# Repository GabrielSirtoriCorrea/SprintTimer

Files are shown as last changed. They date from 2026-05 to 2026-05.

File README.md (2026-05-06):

# SprintTimer
O projeto consiste em um cronômetro destinado à medição de tempos de atletas durante treinamentos de futebol. O sistema baseia-se em um sensor ultrassônico, responsável por detectar a ultrapassagem do atleta em uma marca predefinida, com base na medição de distância. , Um arduino realizará o processamento dos dados para registrar os tempos.

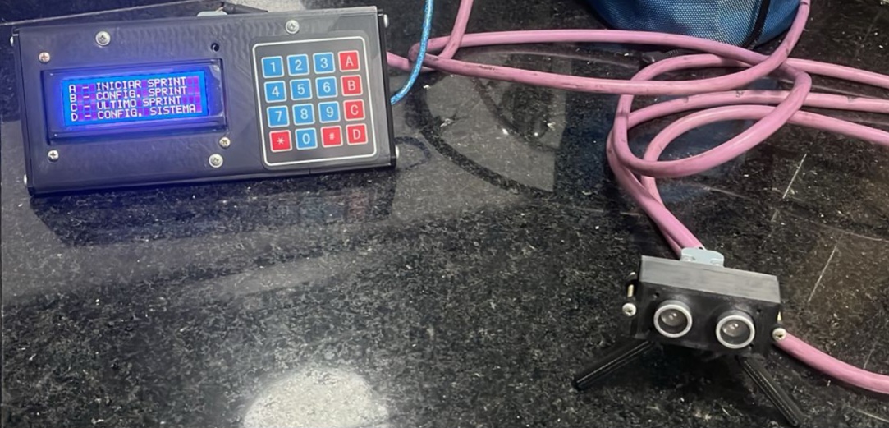
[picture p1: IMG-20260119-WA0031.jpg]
Final

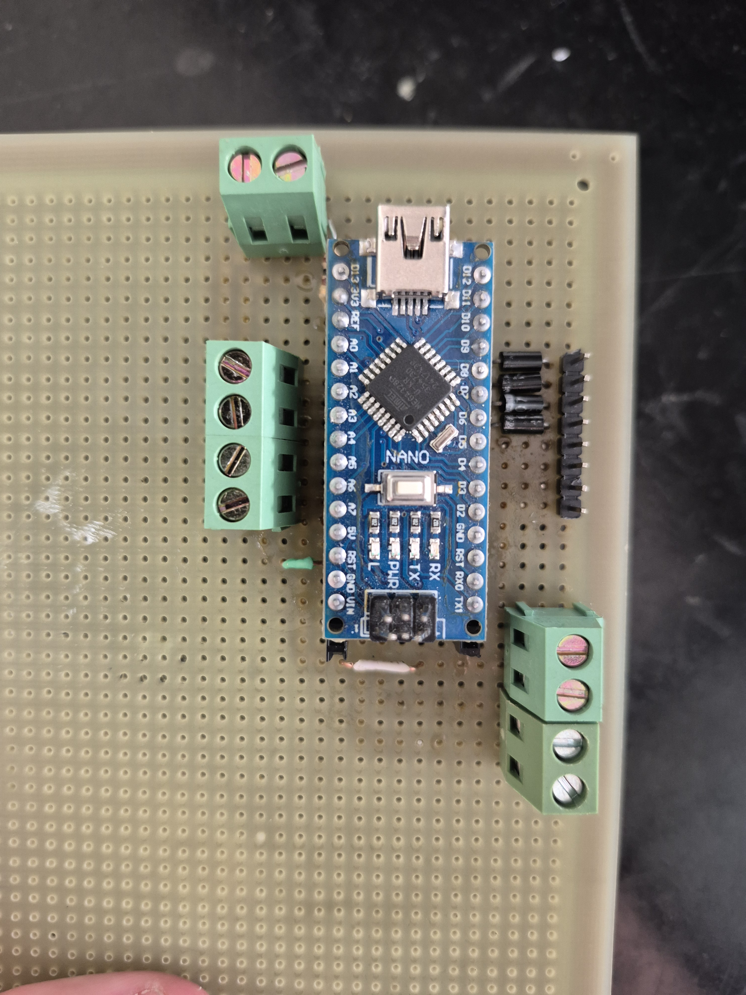
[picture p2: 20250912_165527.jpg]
Circuito Montado

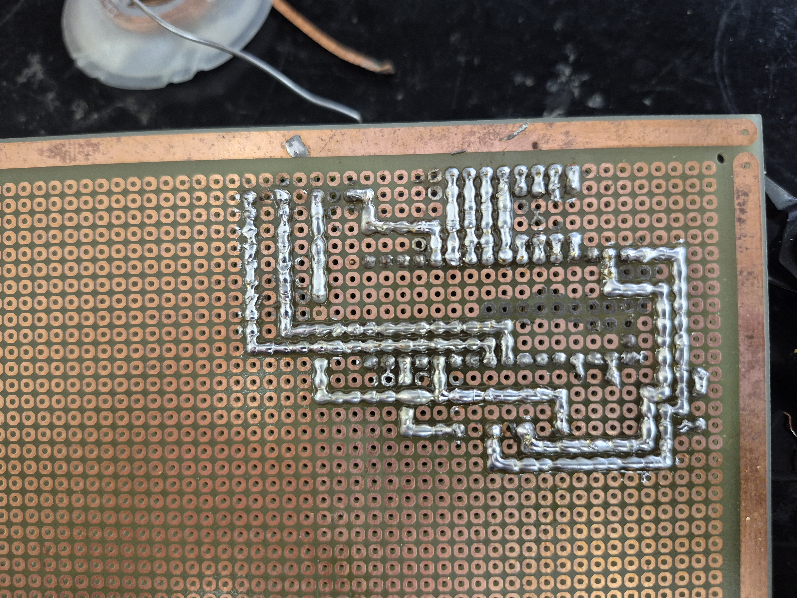
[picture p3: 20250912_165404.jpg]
Solda

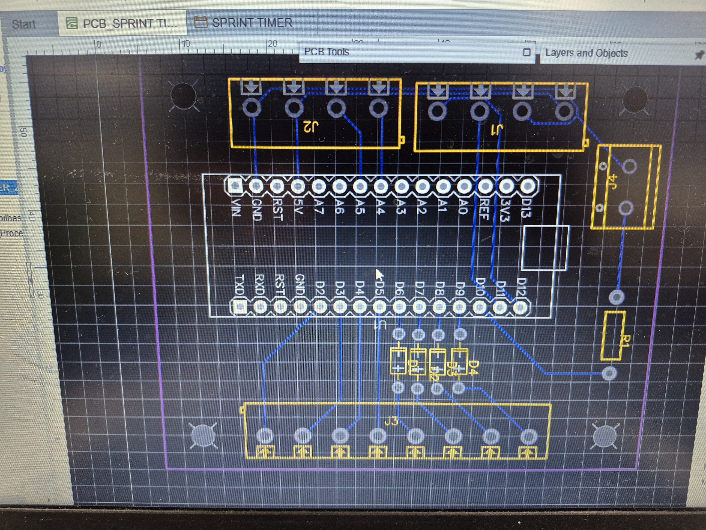
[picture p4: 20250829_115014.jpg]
Projeto


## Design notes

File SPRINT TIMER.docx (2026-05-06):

SPRINT TIMER

Projeto: Gabriel Sirtori Corrêa

Destinado a: Ricardo Roquetti

O presente projeto propõe a criação de um cronômetro destinado à medição de tempos de atletas durante treinamentos de futebol. O sistema será baseado em um sensor ultrassônico, responsável por detectar a ultrapassagem do atleta por uma marca predefinida, com base na medição de distância. As informações captadas pelo sensor serão enviadas a um Arduino Nano, que realizará o processamento dos dados para registrar os tempos com precisão.

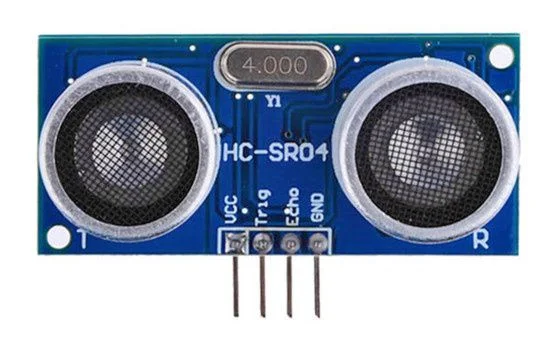
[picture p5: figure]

Sensor ultrassônico a ser utilizado no projeto

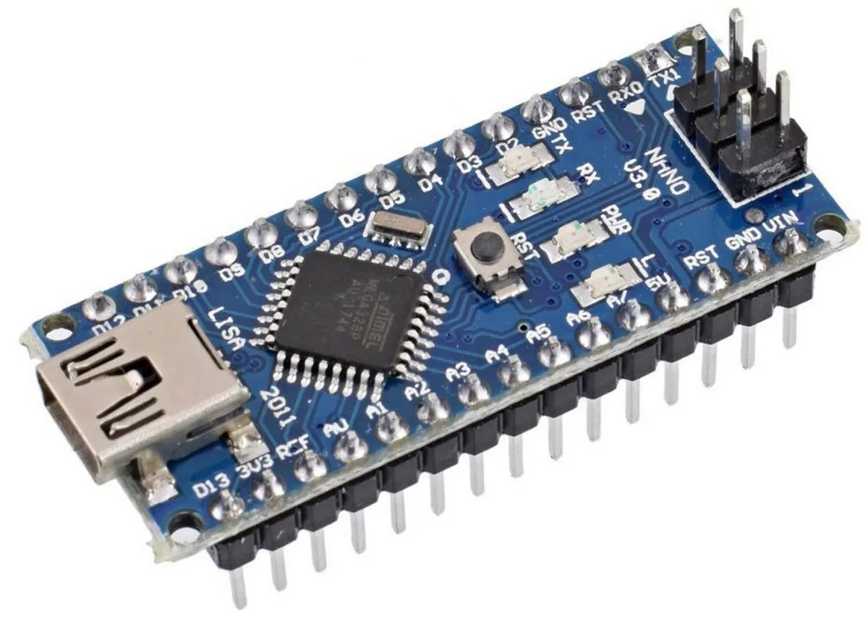
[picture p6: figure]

Arduino nano a ser utilizado no projeto

Junto ao arduino, será conectado um display LCD 20x4 junto a um módulo I2C para comunicação.

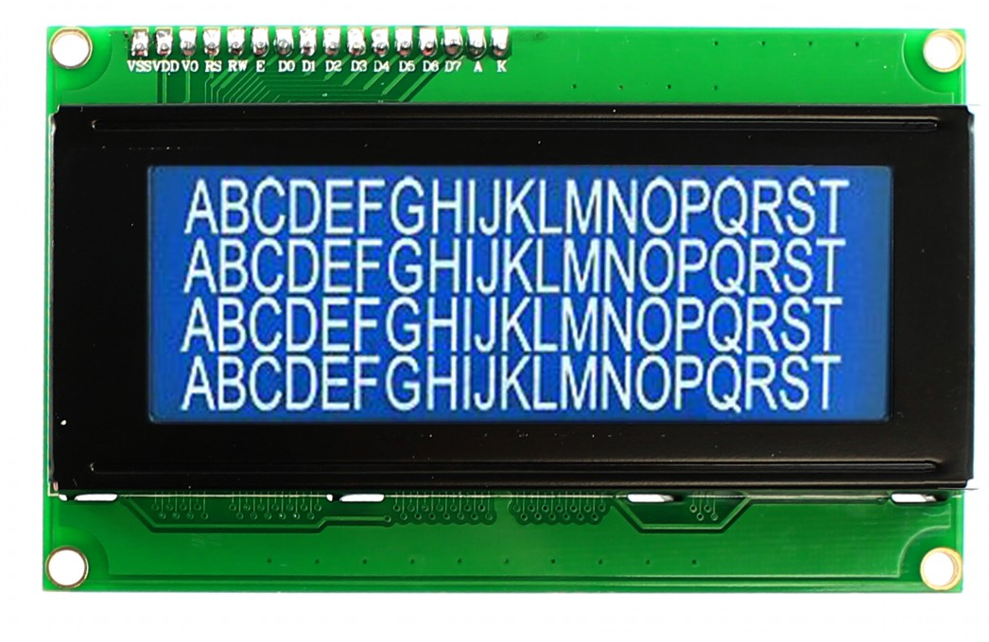
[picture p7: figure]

Display a ser utilizado no projeto

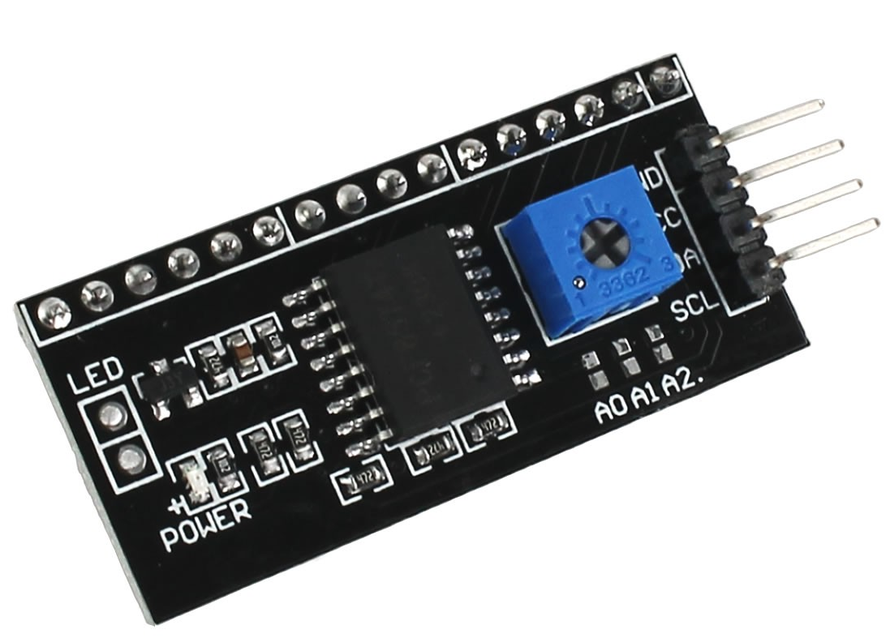
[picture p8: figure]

Display a ser utilizado no projeto

Também será utilizado um alto-falante para avisos sonoros durante os acionamentos dos sensores.

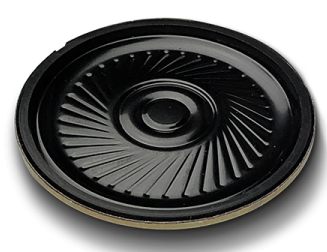
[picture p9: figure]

Alto-falante a ser utilizado no projeto

Para a alimentação do projeto, será utilizada uma fonte chaveada 12V 2A.

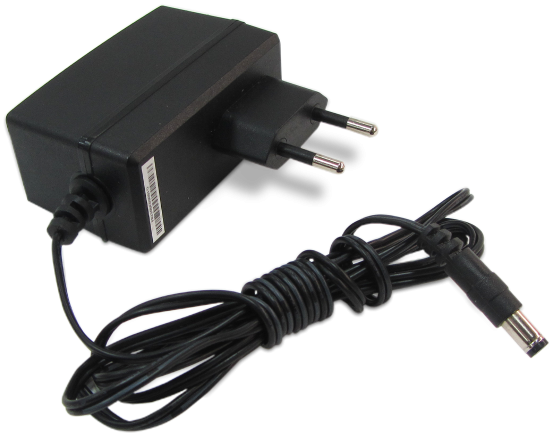
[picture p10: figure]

Fonte a ser utilizada no projeto

A partir de botões e um potenciômetro, usuário poderá configurar o sistema para realizar as seguintes funções

- Calibrar o range de acionamento do sensor;
- Ver a distância atual do sensor;
- Configurar a quantidade de vezes que o sensor será acionado;
- Contagem de tempo;

Essas funcionalidades permitirão ao usuário utilizar o sistema para:

- Determinar uma distância para corrida do atleta;
- Determinar distância de acionamento de chegada;
- Determinar distância de acionamento de início;
- Criar offset de distância para calibração do sensor;
- Contagem de tempo de um sprint;
- Contagem de voltas do atleta;
- Contagem do tempo de cada volta;
- Contagem de tempo total;

Com essas funcionalidades, pode-se criar percursos diferentes e configurar as distâncias necessárias para acionamento do sensor, como no exemplo a seguir:

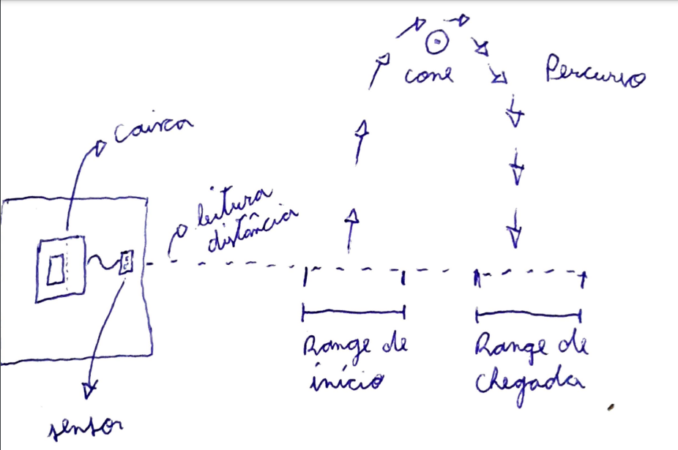
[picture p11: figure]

Exemplo de funcionamento do sistema

É importante ressaltar que o sensor ultrassônico possui um range de operação de 2cm a 4m, dessa forma, a distância entre o mesmo e o final do range de chegada deve-se respeitar esse valor.

O projeto será alocado em uma caixa, com o recorte para o display, botões e potenciômetro, seguindo o exemplo a seguir:

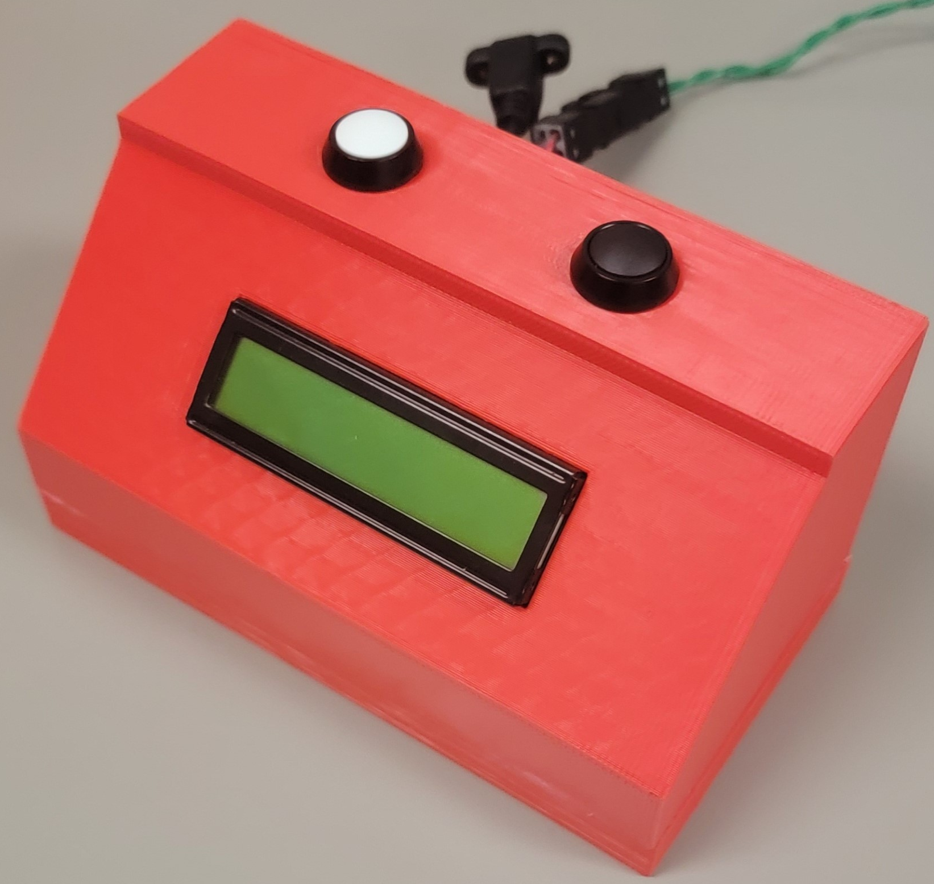
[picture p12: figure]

Caixa do projeto

O sensor ultrassônico será conectado a caixa via cabeamento, e contará com um suporte para apoio.

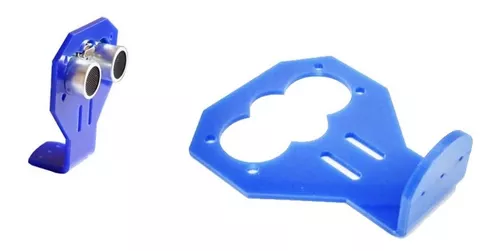
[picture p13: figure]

Suporte para sensor ultrassônico

Será disponibilizado um arquivo 3D contendo o suporte para o sensor e a caixa, que podem ser fabricados através de impressora 3D, máquina de corte a laser ou manualmente.

Com base na descrição apresentada, a lista de materiais e os respectivos valores para a execução deste projeto são os seguintes:

- Materiais:
  - Sensor Ultrasonico - 8,50
  - Arduino nano - 34,90
  - Display LCD 20x4 - 39,90
  - Módulo I2C - 6,90
  - Push buttons - 3,00
  - Alto falante - 3,90
  - Modulo alto falante - 8,90
  - Fonte 9v - 11,50
  - Total: R$117,5
- Projeto:
  - Projeto eletrônico do circuito - R$100,00;
  - Projeto Mecânico do suporte e caixa do sistema - R$100,00;
  - Projeto de programação e lógica do sistema - R$100,00;
  - Total: R$300,00

A remuneração pelo serviço será referente ao projeto do sistema. A aquisição dos materiais e a montagem do projeto ficarão sob responsabilidade do usuário. Propõe-se que o pagamento seja realizado em duas parcelas: 50% no início do projeto, como entrada, e os 50% restantes após a conclusão e entrega do trabalho.

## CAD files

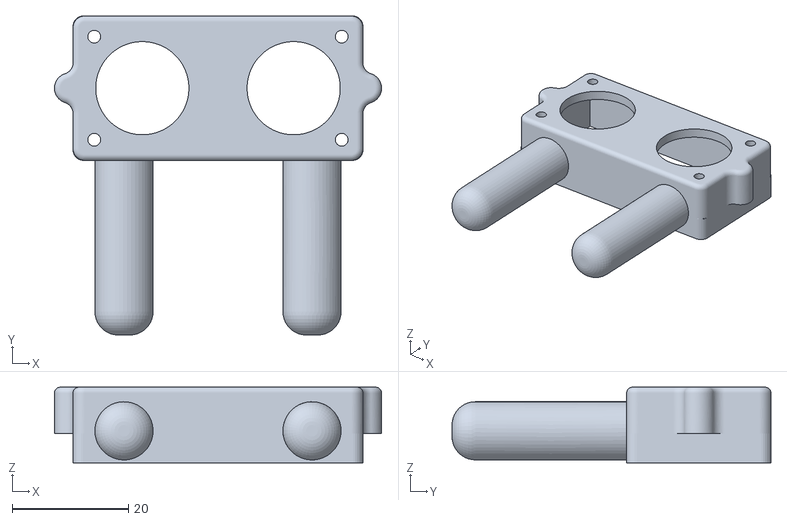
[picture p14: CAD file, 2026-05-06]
Impressão/Frente suporte.stl
56.2 x 54.8 x 13.0

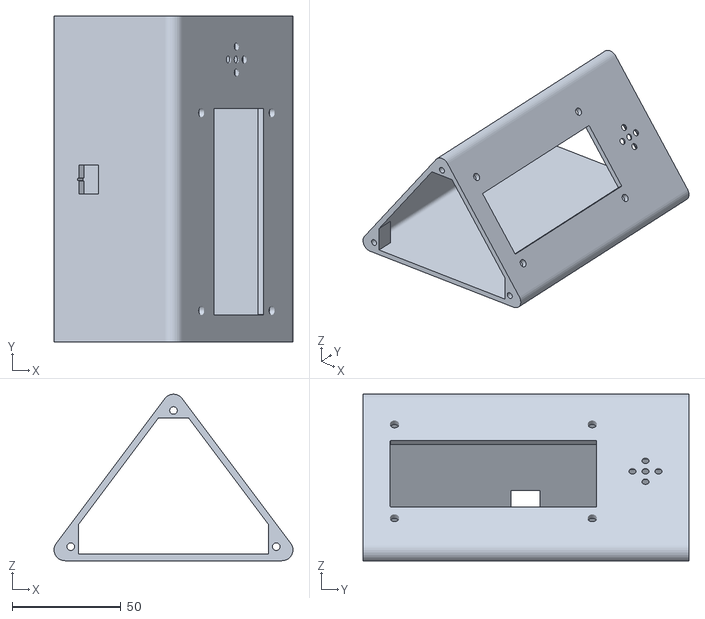
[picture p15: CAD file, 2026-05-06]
Impressão/Estrutura.stl
110.0 x 150.0 x 76.6

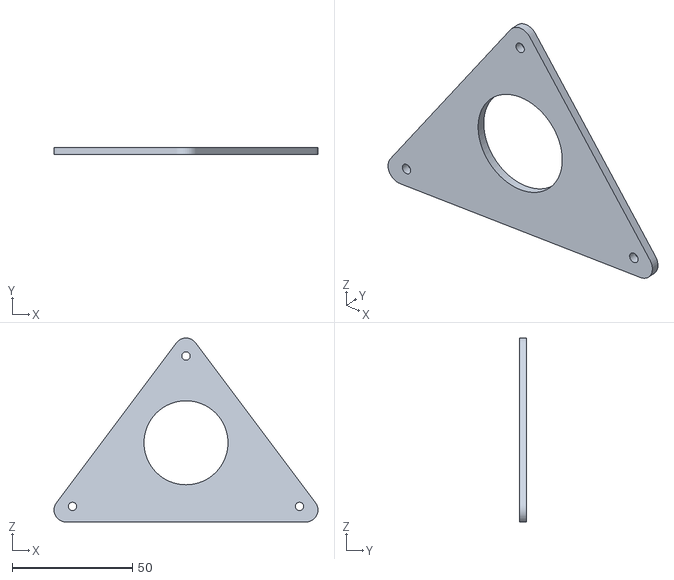
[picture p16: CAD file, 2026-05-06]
Impressão/Tampa 2.stl
110.0 x 3.00 x 76.6

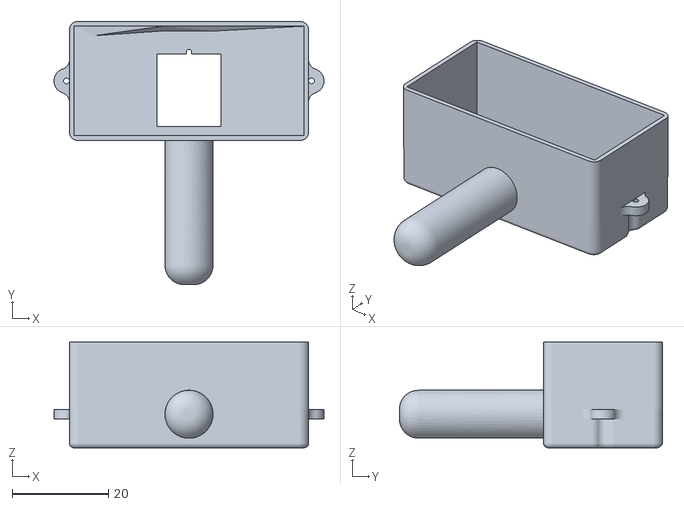
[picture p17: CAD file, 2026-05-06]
Impressão/TrasSuporte.stl
56.2 x 54.8 x 22.0

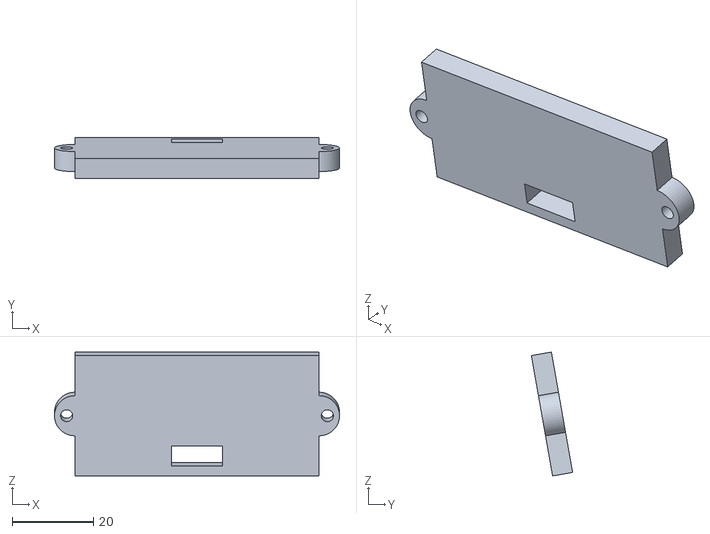
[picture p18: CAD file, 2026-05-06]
Impressão/TampaSuporte.stl
70.0 x 10.1 x 30.4

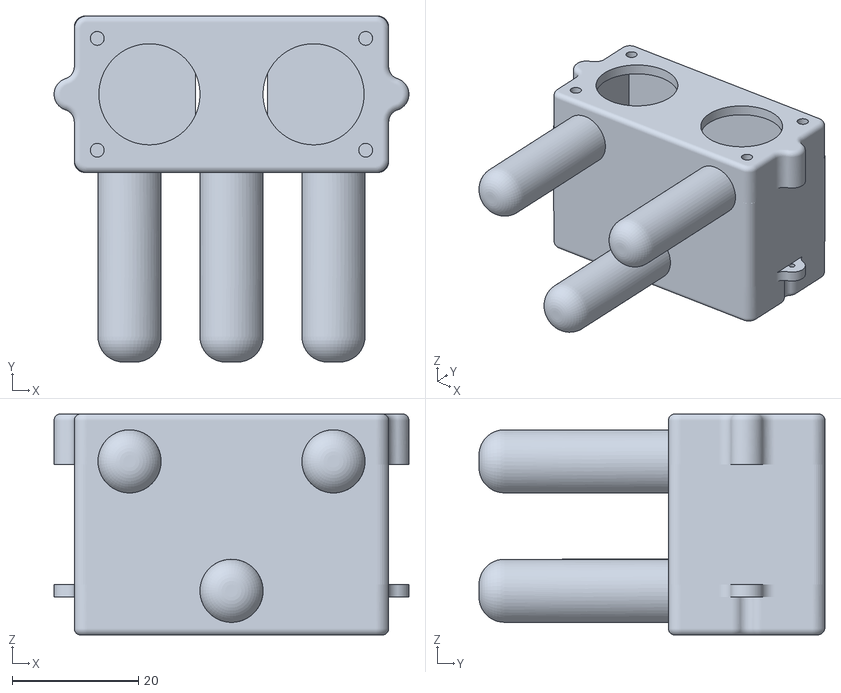
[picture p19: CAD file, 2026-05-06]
Impressão/Suporte.stl
56.2 x 54.8 x 35.0

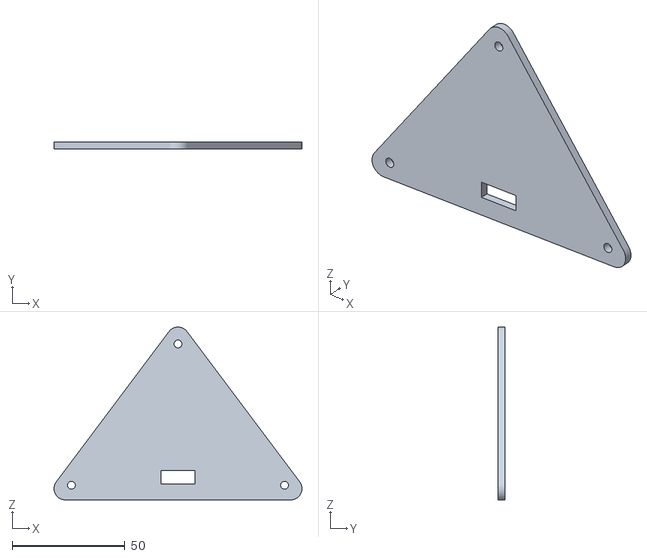
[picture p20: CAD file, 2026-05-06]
Impressão/Lado1.stl
110.0 x 3.00 x 76.6

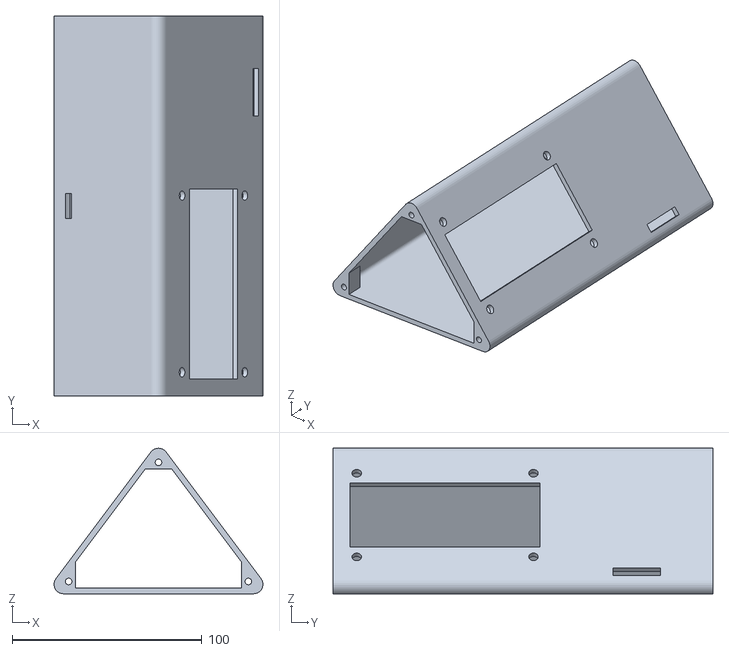
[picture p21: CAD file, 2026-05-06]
Impressão/Nova Case.stl
110.0 x 200.0 x 76.7

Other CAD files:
Impressão/CE2_Lado1 2PRETO.stl
Impressão/FrenteSuporte.stl

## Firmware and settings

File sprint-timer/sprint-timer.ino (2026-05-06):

#include <Key.h>
#include <Keypad.h>

#include <Wire.h>
#include <LiquidCrystal_I2C.h>

#define trigger 11
#define echo 12
#define buzzer 13


LiquidCrystal_I2C lcd(0x27, 20, 4);

float getDistance();
void displayPage(char pageKeyPressed, char lastKey, int currentPage);
void setPage(char pageIndex);

const byte LINHAS = 4; // Linhas do teclado
const byte COLUNAS = 4; // Colunas do teclado

const char TECLAS_MATRIZ[LINHAS][COLUNAS] = { // Matriz de caracteres (mapeamento do teclado)
  {'1', '2', '3', 'A'},
  {'4', '5', '6', 'B'},
  {'7', '8', '9', 'C'},
  {'*', '0', '#', 'D'}
};

const byte PINOS_LINHAS[LINHAS] = {9, 8, 7, 6}; // Pinos de conexao com as linhas do teclado
const byte PINOS_COLUNAS[COLUNAS] = {5, 4, 3, 2}; // Pinos de conexao com as colunas do teclado

Keypad keypadMap = Keypad(makeKeymap(TECLAS_MATRIZ), PINOS_LINHAS, PINOS_COLUNAS, LINHAS, COLUNAS); // Inicia teclado
char keyPressed, lastKeyPressed;
int currentDisplay = 0;
int cursor[2] = {0,0};

float configDistance=0;
float configOffset=0;
float distance=0;

unsigned long startSprintTime;
int sprintTimeSeconds =0;
int sprintTimeMinutes=0;
int sprintTimeTotalSeconds =0;
bool startSprint=false;
bool sprintcount=false;
int firstDistanceDecimal, secondDistanceDecimal, thirdDistanceDecimal;
int firstOffsetDecimal, secondOffsetDecimal, thirdOffsetDecimal;

void setup()
{
  pinMode(trigger, OUTPUT);
  pinMode(echo, INPUT);
  pinMode(buzzer, OUTPUT);
  keypadMap.setDebounceTime(150);
  lcd.init();
  lcd.backlight();
  Serial.begin(9600);
  displayPage(0, 0, 0);
}

void loop(){
  Serial.println(getDistance());
  distance=getDistance();
  //Serial.println(configOffset);
  setPage(currentDisplay);
  keyPressed = keypadMap.getKey();

  if (keyPressed) {
    tone(buzzer, 5000, 100);
    Serial.println(keyPressed);
    displayPage(keyPressed, lastKeyPressed, currentDisplay);
    lastKeyPressed=keyPressed;
  }
	
}

float getDistance(){
  float distance;
  float seconds;
  
  digitalWrite(trigger, LOW);
  delayMicroseconds(2);
  digitalWrite(trigger, HIGH);
  delayMicroseconds(10);
  digitalWrite(trigger, LOW);
  delayMicroseconds(2);
  seconds = pulseIn(echo, HIGH);
  distance = ((seconds * (344 * 0.0001))/2);
  if(distance>99.99)
    distance = 99.99;
  return distance;
}


void setPage(char pageIndex){
  char pageKey = pageIndex;
  switch(pageKey){
    case 0:
      lcd.setCursor(4,1);
      lcd.print("SPRINT TIMER");
      break;

    case 1:
      lcd.setCursor(0,0);
      lcd.print("A - INICIAR SPRINT");
      lcd.setCursor(0,1);
      lcd.print("B - CONFIG. SPRINT");
      lcd.setCursor(0,2);
      lcd.print("C - ULTIMO SPRINT");
      lcd.setCursor(0,3);
      lcd.print("D - CONFIG. SISTEMA");
      break;

    case 2:
      if(startSprint){
        lcd.setCursor(4, 2);
        lcd.print("PARAR  ");
        if(distance<configOffset){
          if(!sprintcount){
            sprintcount=true;
            startSprintTime=millis();
          }else if(sprintTimeSeconds>5){
            startSprint=false;
            sprintcount=false;
            lcd.setCursor(4, 2);
            lcd.print("FINALIZADO");
            delay(2000);
            lcd.clear();
            currentDisplay=4;
          }
        }
        if(sprintcount){
          Serial.print("segundos: ");
          Serial.println(sprintTimeSeconds);
          Serial.print("tempo: ");
          Serial.println(millis());
          sprintTimeTotalSeconds = (millis() - startSprintTime)/1000;
          sprintTimeSeconds = sprintTimeTotalSeconds%60;
          sprintTimeMinutes = (sprintTimeTotalSeconds/60)%60;
          lcd.setCursor(7, 1);
          if(sprintTimeMinutes<10){
            lcd.print("0");
            lcd.setCursor(8, 1);
          }
          lcd.print(sprintTimeMinutes);

          lcd.setCursor(9, 1);
          lcd.print(":");
            
          lcd.setCursor(10, 1);
          if(sprintTimeSeconds<10){
            lcd.print("0");
            lcd.setCursor(11, 1);
          }
          lcd.print(sprintTimeSeconds);
        }
      }else{
        lcd.setCursor(0,0);      
        lcd.print("DISTANCIA: ");
        lcd.setCursor(15,0);      
        lcd.print("m");
        lcd.setCursor(0,1);
        lcd.print("TEMPO: ");
        lcd.setCursor(0,2);
        lcd.print("A - INICIAR");
      }

      break;

    case 3:
      lcd.setCursor(0,0);
      lcd.print("DISTANCIA: ");
      lcd.setCursor(15,0);
      lcd.print("m");
      lcd.setCursor(0,1);
      lcd.print("OFFSET: ");
      lcd.setCursor(12,1);
      lcd.print("cm");
      lcd.setCursor(0,3);
      lcd.print("[C] -> Mover cursor");
      if(cursor[0]==0){
        cursor[0]=10;
      }
      lcd.setCursor(cursor[0], cursor[1]);
      break;

    case 4:
      lcd.setCursor(0,0);
      lcd.print("DISTANCIA: ");
      lcd.setCursor(11,0);
      lcd.print(configDistance);
      lcd.setCursor(0,1);
      lcd.print("TEMPO: ");
      lcd.setCursor(7,1);lcd.setCursor(7, 1);
      if(sprintTimeMinutes<10){
          lcd.print("0");
          lcd.setCursor(8, 1);
      }
      lcd.print(sprintTimeMinutes);

      lcd.setCursor(9, 1);
      lcd.print(":");
            
      lcd.setCursor(10, 1);
      if(sprintTimeSeconds<10){
        lcd.print("0");
        lcd.setCursor(11, 1);
      }
      lcd.print(sprintTimeSeconds);
      lcd.setCursor(0,2);
      lcd.print("VEL.: ");
      lcd.setCursor(6,2);
      lcd.print(configDistance/((float) sprintTimeTotalSeconds));
      lcd.setCursor(10,2);
      lcd.print("m/s");
      
      break;

    case 5:
      lcd.setCursor(0,0);
      lcd.print("UN. DISTANCIA: m/s");
      lcd.setCursor(0,1);
      lcd.print("UN. TEMPO: segundo");
      lcd.setCursor(0,2);
      lcd.print("UN. VELOC.: m/s");
      lcd.setCursor(5,3);
      lcd.print("[C] <[D]");
      break;
  }
}

void displayPage(char pageKeyPressed, char lastKey, int currentPage){
  char pageKey = pageKeyPressed;
  if(currentPage == 0){
    lcd.setCursor(4,1);
    lcd.print("SPRINT TIMER");
    
    switch(pageKey){
      case '#':
        currentDisplay=1;
        lcd.clear();
          break;
    } 

  }else if(currentPage == 1){
    switch(pageKey){
      case 'A':
        lcd.clear();
        currentDisplay=2;
        lcd.setCursor(11, 0);
        if(configDistance<10.0){
          lcd.print("0");
          lcd.setCursor(12, 0);
        }
        lcd.print(configDistance, 1);
        
        lcd.setCursor(7, 1);
        if(sprintTimeMinutes<10){
          lcd.print("0");
          lcd.setCursor(8, 1);
        }
        lcd.print(sprintTimeMinutes);

        lcd.setCursor(9, 1);
        lcd.print(":");
          
        lcd.setCursor(10, 1);
        if(sprintTimeSeconds<10){
          lcd.print("0");
          lcd.setCursor(11, 1);
        }
        lcd.print(sprintTimeMinutes);
        break;

      case 'B':
        currentDisplay=3;   
        lcd.clear();
        lcd.setCursor(11, 0);
        if(configDistance<10.0){
          lcd.print("0");
          lcd.setCursor(12, 0);
        }
        lcd.print(configDistance, 1);
        lcd.setCursor(8, 1);
        if(configOffset<10.0){
          lcd.print("0");
          lcd.setCursor(9, 1);
        }
        lcd.print(configOffset, 1);
        break;

      case 'C':
        currentDisplay=4;    
        lcd.clear();
        break;

      case 'D':
        currentDisplay=5;    
        lcd.clear();
        break;

      case '*':
        currentDisplay=0;  
        lcd.clear();
        break;

      case '#':
        break;
    }
  }else if(currentPage == 2){
    switch(pageKey){
      case '*':
        startSprint=false;
        sprintcount=false;
        sprintTimeTotalSeconds=0;
        lcd.clear();
        currentDisplay=1;
        break;

      case 'A':
        startSprint=true;   
        break;
    }
  }else if(currentPage == 3){
    switch(pageKey){
      case '*':
        currentDisplay=1;
        configDistance = (firstDistanceDecimal*10)+secondDistanceDecimal+(thirdDistanceDecimal/10.0);
        configOffset = (firstOffsetDecimal*10)+secondOffsetDecimal+(thirdOffsetDecimal/10.0);
        Serial.println(configDistance);
        lcd.clear();
        break;

      case 'C':
        if(lastKey == 'C'){
          if(cursor[1]==0){
            switch(cursor[0]){
              case 11:   
                lcd.print(firstDistanceDecimal);
                break;
              case 12:
                lcd.print(secondDistanceDecimal);
                break;
              case 14:
                lcd.print(thirdDistanceDecimal);
                break;
            }
          }else if(cursor[1]==1){
            switch(cursor[0]){
              case 8:   
                lcd.print(firstOffsetDecimal);
                break;
              case 9:
                lcd.print(secondOffsetDecimal);
                break;
              case 11:
                lcd.print(thirdOffsetDecimal);
                break;
            }
          }
        }
        cursor[0]++;
        if(((cursor[0]==13) && (cursor[1]==0) || (cursor[0]==10) && (cursor[1]==1))){
          cursor[0]++;
        }else if((cursor[0]==15) && (cursor[1]==0)){
          cursor[0]=8;
          cursor[1]=1;
        }else if((cursor[0]==12) && (cursor[1]==1)){
          cursor[0]=11;
          cursor[1]=0;
        }
        lcd.setCursor(cursor[0], cursor[1]);
        lcd.print("_");
        break;	

      default:
        lcd.print(pageKey);
        if((cursor[0]==11)&&(cursor[1]==0)){
          firstDistanceDecimal=pageKey - '0';
        }else if((cursor[0]==12)&&(cursor[1]==0)){
          secondDistanceDecimal=pageKey - '0';
        }else if((cursor[0]==14)&&(cursor[1]==0)){
          thirdDistanceDecimal=pageKey - '0';
        }else if((cursor[0]==8)&&(cursor[1]==1)){
          firstOffsetDecimal=pageKey - '0';
        }else if((cursor[0]==9)&&(cursor[1]==1)){
          secondOffsetDecimal=pageKey - '0';
        }else if((cursor[0]==11)&&(cursor[1]==1)){
          thirdOffsetDecimal=pageKey - '0';
        }
        break;
    }
  }else if(currentPage == 4){ 
    switch(pageKey){
      case '*':
        currentDisplay=1;    
        lcd.clear();
        break;
    }
  }else if(currentPage == 5){
    switch(pageKey){
      case '*':
        currentDisplay=1;    
        lcd.clear();
        break;
    }
  }
}

void moveCursorRight(int currentPage, char key){
  switch(currentPage){
    case 3:
      if(key==1024){
        cursor[0]++;
        lcd.setCursor(cursor[0], cursor[1]);
        lcd.print(key);
      }
      break;

    case 4:
      lcd.setCursor(0,0);
      lcd.print("DISTANCIA: 0,0m");
      lcd.setCursor(0,1);
      lcd.print("TEMPO: 0,0s");
      lcd.setCursor(0,2);
      lcd.print("VELOCIDADE: 0,0m/s");
      break;

    case 5:
      lcd.setCursor(0,0);
      lcd.print("UN. DISTANCIA: m/s");
      lcd.setCursor(0,1);
      lcd.print("UN. TEMPO: segundo");
      lcd.setCursor(0,2);
      lcd.print("UN. VELOC.: m/s");
      lcd.setCursor(5,3);
      lcd.print(">[C] <[D]");
      break;
  }
}
